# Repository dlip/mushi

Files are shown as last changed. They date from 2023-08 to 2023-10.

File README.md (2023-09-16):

# Mushi Keyboard

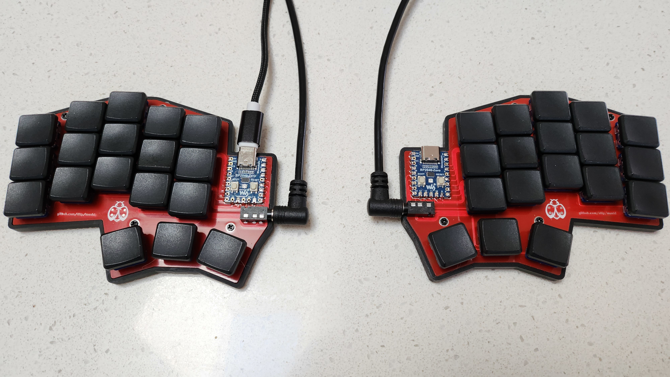
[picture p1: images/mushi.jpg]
Mushi Keyboard


Mushi (Japanese for bug) is a simple 36 key split ergonomic keyboard.

## Features

- Uses 2 cheap RP2040-Zero MCU
- Low profile Choc switches
- Hot swappable (optional)
- Requires no diodes
- Inner thumb splay to make it easier to reach
- Created with [Ergogen](https://github.com/ergogen/ergogen) and [KiCad](https://www.kicad.org)

## Build Your Own

### Board

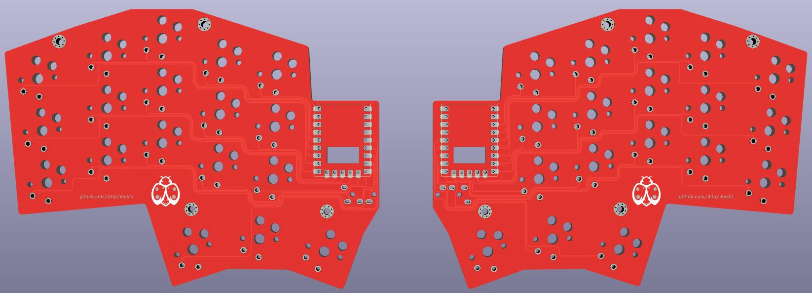
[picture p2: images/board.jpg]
Board


#### Parts

- Send the [Gerber](kicad/gerber_to_order) file to the PCB manufacturer of your choice
- 2 x RP2040-Zero
- 2 x TRRS socket
- 1 x TRRS cable
- 36 x low profile choc switches and keycaps
- (optional) 36 x kailh hotswap sockets
- (optional) RP2040-Zero headers

#### Instructions

- Solder the RP2040-Zeros to the board either directly or using the headers you purchased
- Build and flash the firmware
- [QMK](https://github.com/dlip/qmk_firmware/tree/dlip/keyboards/mushi)

Left side

```
qmk flash -kb mushi -km default -bl uf2-split-left
```

Right side

```
qmk flash -kb mushi -km default -bl uf2-split-right
```

- You can test the boards at this point by connecting the hotswap pads with some metal tweezers before continuing
- Solder the kalih hotswap sockets if purchased or solder the switches directly the board otherwise
- Solder the TRRS sockets to the board
- Insert the switches into the hotswap sockets if necessary
- Add your keycaps
- Connect TRRS cable before connecting the usb cable and remember to disconnect it after disconnecting the usb cable
- Create your own keymap by forking my repo and either modifying the default keymap or copying it to a new name and changing 'default' in the flash command

### Case

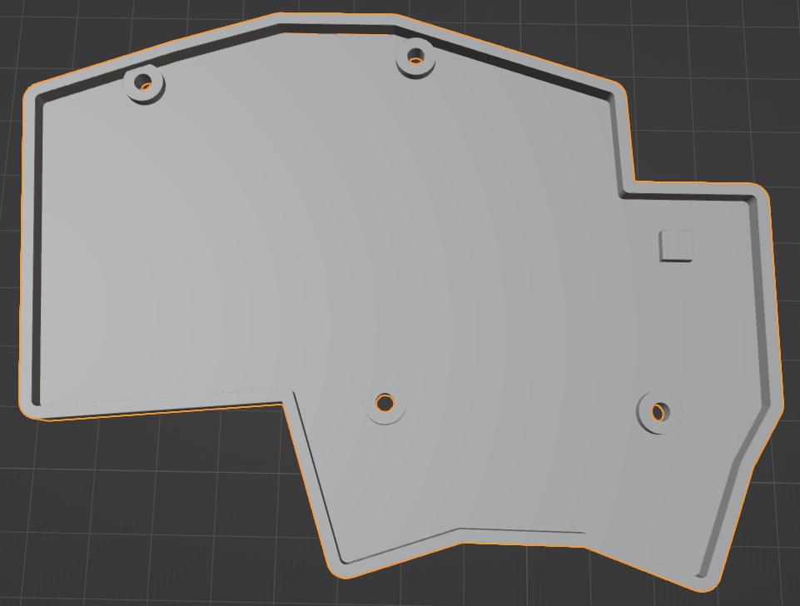
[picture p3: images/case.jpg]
Case


#### Parts

- 3D print the left and right cases in the [case](case/) folder
- 8 x Knurled Insert Nuts (M2 x 3mm Length x 3.2mm OD) [example](https://www.amazon.com/dp/B07LBQFNQD)
- 8 x M2 3mm flat screws [example](https://www.amazon.com/gp/product/B01FTI8TM8/)
- 10-16 x Rubber feet

#### Instructions

- Use a soldering iron to melt the insert nuts into the holes in the cases
- Screw the boards to the cases
- Stick rubber feet to bottom

### Credits

- alinelena for checking my work and helping me make such beautiful tracks
- logturnal for the cool [bug logo](https://www.freepik.com/free-vector/ladybug-simple-mascot-logo-design-illustration_57161077.htm)

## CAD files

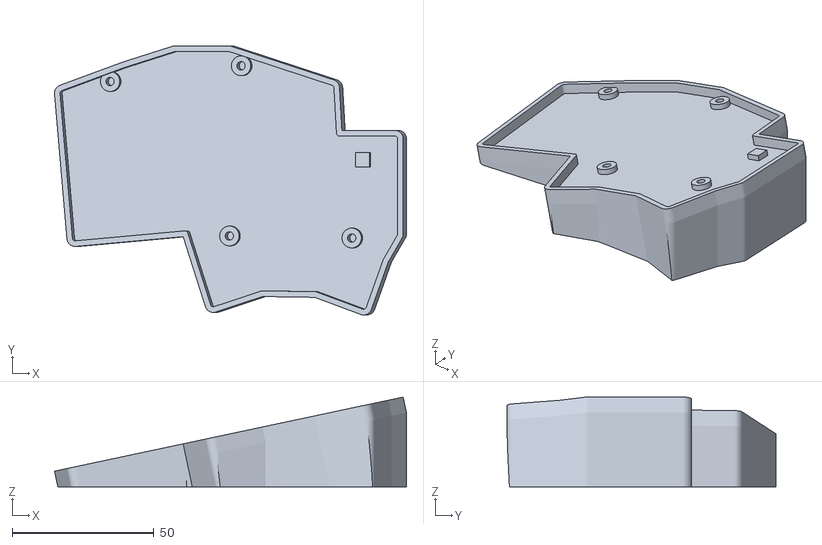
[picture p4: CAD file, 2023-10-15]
case/tenting.stl
124.1 x 94.8 x 31.7

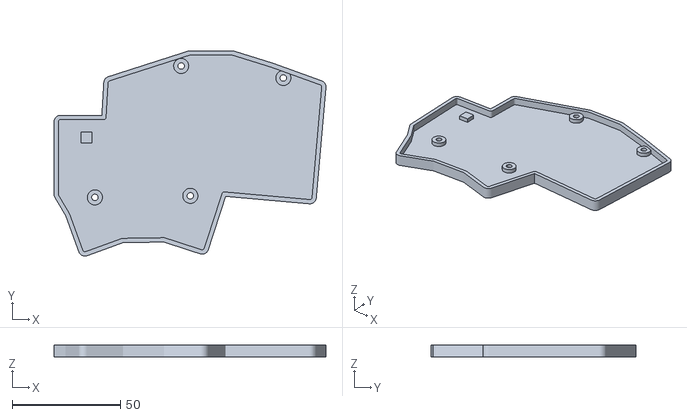
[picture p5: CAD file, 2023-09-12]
case/caseRight.stl
125.7 x 94.8 x 5.60

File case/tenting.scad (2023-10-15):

$fn = 40;
tent = 12;

intersection() {
	linear_extrude(100) rotate([0, -tent, 0]) translate([-14,0,0])  import("../output/outlines/xlBoardLeft.dxf", convexity=10);
	translate([0,0,0]) rotate([0, -tent, 0])	translate([-14,0,-100]) linear_extrude(100) import("../output/outlines/xlBoardLeft.dxf", convexity=10);
}
rotate([0, -tent, 0])	translate([-14,0,0]) import("caseLeft.stl", convexity=10);

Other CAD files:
case/caseLeft.stl

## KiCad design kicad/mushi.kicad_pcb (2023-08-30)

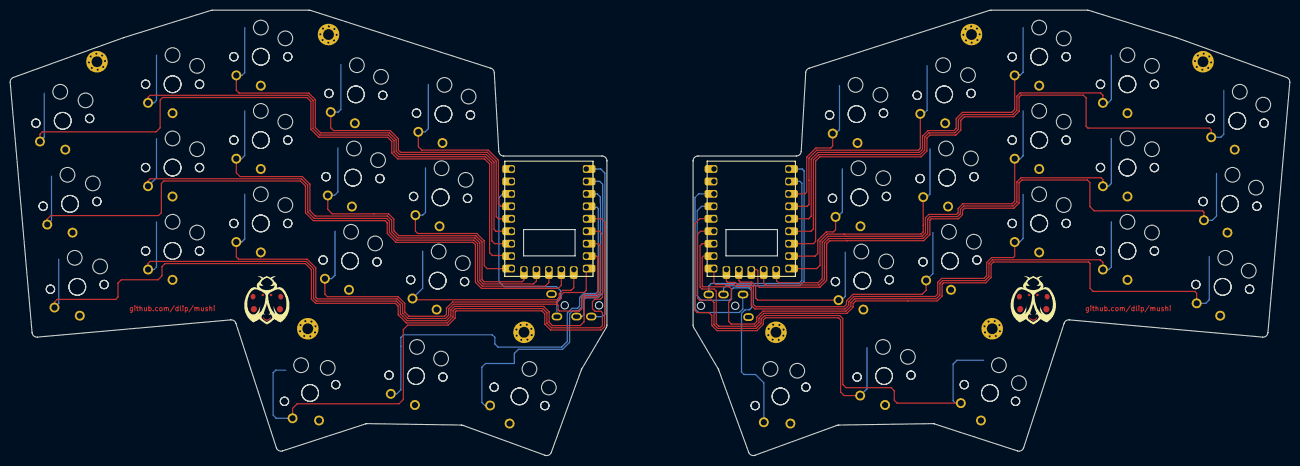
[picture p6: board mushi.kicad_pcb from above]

Board: 2 copper layers, 261.0 x 90.8 mm, 84 parts (0 on the bottom side), 44 nets.

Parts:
RP2040Zero1, RP2040Zero2: RP2040-Zero
S1, S2, S3, S4, S5, S6, S7, S8, S9, S10, S11, S12, S13, S14, S15, S16, S17, S18, S19, S20, S21, S22, S23, S24, S25, S26, S27, S28, S29, S30, S31, S32, S33, S34, S35, S36, S37, S38, S39, S40, S41, S42, S43, S44, S45, S46, S47, S48, S49, S50, S51, S52, S53, S54, S55, S56, S57, S58, S59, S60, S61, S62, S63, S64, S65, S66, S67, S68, S69, S70, S71, S72: PG1350
TRRS1, TRRS2: TRRS-PJ-320A-dual
_1, _2, _3, _4, _5, _6, _7, _8: MountingHole_2.2mm_M2_Pad_Via

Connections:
GND: RP2040Zero1.20, S1.2, S2.2, S3.2, S4.2, S5.2, S6.2, S7.2, S8.2, S9.2, S10.2, S11.2, S12.2, S13.2, S14.2, S15.2, S16.2, S17.2, S18.2, S19.2, S20.2, S21.2, S22.2, S23.2, S24.2, S25.2, S26.2, S27.2, S28.2, S29.2, S30.2, S31.2, S32.2, S33.2, S34.2, S35.2, S36.2, TRRS1.1
P3V3: RP2040Zero1.21, TRRS1.2
RX: RP2040Zero1.2, TRRS1.3
TX: RP2040Zero1.1, TRRS1.4
matrix_index_bottom: RP2040Zero1.9, S10.1, S28.1
matrix_index_middle: RP2040Zero1.14, S11.1, S29.1
matrix_index_top: RP2040Zero1.22, S12.1, S30.1
matrix_middle_bottom: RP2040Zero1.8, S7.1, S25.1
matrix_middle_middle: RP2040Zero1.13, S8.1, S26.1
matrix_middle_top: RP2040Zero1.18, S9.1, S27.1
matrix_outer_bottom: RP2040Zero1.10, S13.1, S31.1
matrix_outer_middle: RP2040Zero1.15, S14.1, S32.1
matrix_outer_top: RP2040Zero1.23, S15.1, S33.1
matrix_pinky_bottom: RP2040Zero1.6, S1.1, S19.1
matrix_pinky_middle: RP2040Zero1.11, S2.1, S20.1
matrix_pinky_top: RP2040Zero1.16, S3.1, S21.1
matrix_ring_bottom: RP2040Zero1.7, S4.1, S22.1
matrix_ring_middle: RP2040Zero1.12, S5.1, S23.1
matrix_ring_top: RP2040Zero1.17, S6.1, S24.1
mirror_matrix_index_bottom: RP2040Zero2.14, S46.1, S64.1
mirror_matrix_index_middle: RP2040Zero2.9, S47.1, S65.1
mirror_matrix_index_top: RP2040Zero2.4, S48.1, S66.1
mirror_matrix_middle_bottom: RP2040Zero2.15, S43.1, S61.1
mirror_matrix_middle_middle: RP2040Zero2.10, S44.1, S62.1
mirror_matrix_middle_top: RP2040Zero2.5, S45.1, S63.1
mirror_matrix_outer_bottom: RP2040Zero2.13, S49.1, S67.1
mirror_matrix_outer_middle: RP2040Zero2.8, S50.1, S68.1
mirror_matrix_outer_top: RP2040Zero2.3, S51.1, S69.1
mirror_matrix_pinky_bottom: RP2040Zero2.17, S37.1, S55.1
mirror_matrix_pinky_middle: RP2040Zero2.12, S38.1, S56.1
mirror_matrix_pinky_top: RP2040Zero2.7, S39.1, S57.1
mirror_matrix_ring_bottom: RP2040Zero2.16, S40.1, S58.1
mirror_matrix_ring_middle: RP2040Zero2.11, S41.1, S59.1
mirror_matrix_ring_top: RP2040Zero2.6, S42.1, S60.1
mirror_thumbs_inner_cluster: RP2040Zero2.18, S52.1, S70.1
mirror_thumbs_middle_cluster: RP2040Zero2.22, S53.1, S71.1
mirror_thumbs_outer_cluster: RP2040Zero2.23, S54.1, S72.1
rGND: RP2040Zero2.20, S37.2, S38.2, S39.2, S40.2, S41.2, S42.2, S43.2, S44.2, S45.2, S46.2, S47.2, S48.2, S49.2, S50.2, S51.2, S52.2, S53.2, S54.2, S55.2, S56.2, S57.2, S58.2, S59.2, S60.2, S61.2, S62.2, S63.2, S64.2, S65.2, S66.2, S67.2, S68.2, S69.2, S70.2, S71.2, S72.2, TRRS2.1
rP3V3: RP2040Zero2.21, TRRS2.2
rRX: RP2040Zero2.2, TRRS2.4
rTX: RP2040Zero2.1, TRRS2.3
thumbs_inner_cluster: RP2040Zero1.5, S16.1, S34.1
thumbs_middle_cluster: RP2040Zero1.4, S17.1, S35.1
thumbs_outer_cluster: RP2040Zero1.3, S18.1, S36.1

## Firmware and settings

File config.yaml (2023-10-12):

units:
  # Proxy Spacing Variables
  kx: cx
  ky: cy
  # Padding Variables
  px: kx + 2
  py: ky + 2
  # Double Padding Variables
  dpx: kx + 8
  dpy: ky + 8
  # M2 Screw Inserts
  screwRadius: 1.50
  standoffThickness: 2
  standoffDepth: 2
  # Case
  pcbThickness: 1.6
  baseThickness: 2
  wallThickness: 2
  # Footprints
  rp2040zero_x: 18
  rp2040zero_y: 23.5
  trrs_x: 12
  trrs_y: 6
points:
  zones:
    matrix:
      anchor:
        shift: [30, -80]
      key:
        padding: 1ky
        spread: 1kx
      columns:
        pinky:
          key:
            splay: 5
        ring:
          key:
            stagger: 0.33ky
            splay: -5
            spread: 1kx + 2
        middle:
          key:
            stagger: 0.33ky
        index:
          key:
            stagger: -0.45ky
            splay: -2
            spread: 1kx + 0.2
        outer:
          key:
            stagger: -0.2ky
            spread: 1kx
      rows:
        bottom:
        middle:
        top:
    thumbs:
      key:
        padding: 1kx
        spread: 1ky
      anchor:
        ref: matrix_outer_bottom
        shift: [-1.4kx, -1.4ky]
      columns:
        inner:
          key:
            width: 1.5kx
            splay: 20
        middle:
          key:
            width: 1.5kx
            splay: -20
            spread: 1.2kx
            stagger: -0.2ky
        outer:
          key:
            width: 1.5kx
            splay: -18
            spread: 1.25ky
            stagger: -0.2ky
      rows:
        cluster:
    mcu:
      anchor:
        ref: matrix_middle_top
        shift: [3.2kx, -2ky]
      key:
        width: rp2040zero_x
        height: rp2040zero_y
    trrs:
      anchor:
        ref: mcu
        shift: [7, -rp2040zero_x]
      key:
        width: trrs_x
        height: trrs_y
    holePinkyTop:
      anchor:
        ref: [matrix_pinky_top]
        shift: [0.4px,0.6py]
    holeIndexTop:
      anchor:
        ref: [matrix_index_top]
        shift: [-0.3px, 12]
    holeInnerThumbs:
      anchor:
        ref: [thumbs_inner_cluster]
        shift: [0.2kx, 0.7kx]
    holeOuterThumbs:
      anchor:
        ref: [thumbs_outer_cluster]
        shift: [-0.2kx, 0.7kx]
    support:
      anchor:
        ref: [mcu]
        shift: [0, 0.3kx]
  mirror: &mirror
    ref: matrix_index_top
    distance: 120
outlines:
  keys:
    - what: rectangle
      where: /matrix|thumb/
      size: [kx-0.5,ky-0.5]
  boardLeft:
    - what: polygon
      operation: stack
      fillet: 1
      points:
        - ref: matrix_pinky_top
          shift: [-0.5px,0.5py]
        - ref: matrix_ring_top
          shift: [-0.5px,0.5py]
        - ref: matrix_middle_top
          shift: [-0.5px,0.5py]
        - ref: matrix_middle_top
          shift: [0.5px,0.5py]
        - ref: matrix_outer_top
          shift: [0.5px,0.5py]
        - ref: mcu
          shift: [-rp2040zero_x/2,rp2040zero_y/2+2]
        - ref: mcu
          shift: [rp2040zero_x/2+4,rp2040zero_y/2+2]
        - ref: trrs
          shift: [trrs_x/2,-trrs_y/2]
        - ref: thumbs_outer_cluster
          shift: [0.5px,0.5py]
        - ref: thumbs_outer_cluster
          shift: [0.5px,-0.5py]
        - ref: thumbs_outer_cluster
          shift: [-0.45px,-0.5py]
        - ref: thumbs_inner_cluster
          shift: [0.45px,-0.5py]
        - ref: thumbs_inner_cluster
          shift: [-0.5px,-0.5py]
        - ref: thumbs_inner_cluster
          shift: [-0.5px,1py]
        - ref: matrix_pinky_bottom
          shift: [-0.5px,-0.5py]
  boardRight:
    - what: polygon
      operation: stack
      fillet: 1
      points:
        - ref: mirror_matrix_pinky_top
          shift: [-0.5px,0.5py]
        - ref: mirror_matrix_ring_top
          shift: [-0.5px,0.5py]
        - ref: mirror_matrix_middle_top
          shift: [-0.5px,0.5py]
        - ref: mirror_matrix_middle_top
          shift: [0.5px,0.5py]
        - ref: mirror_matrix_outer_top
          shift: [0.5px,0.5py]
        - ref: mirror_mcu
          shift: [-rp2040zero_x/2,rp2040zero_y/2+2]
        - ref: mirror_mcu
          shift: [rp2040zero_x/2+4,rp2040zero_y/2+2]
        - ref: mirror_trrs
          shift: [trrs_x/2,-trrs_y/2]
        - ref: mirror_thumbs_outer_cluster
          shift: [0.5px,0.5py]
        - ref: mirror_thumbs_outer_cluster
          shift: [0.5px,-0.5py]
        - ref: mirror_thumbs_outer_cluster
          shift: [-0.45px,-0.5py]
        - ref: mirror_thumbs_inner_cluster
          shift: [0.45px,-0.5py]
        - ref: mirror_thumbs_inner_cluster
          shift: [-0.5px,-0.5py]
        - ref: mirror_thumbs_inner_cluster
          shift: [-0.5px,1py]
        - ref: mirror_matrix_pinky_bottom
          shift: [-0.5px,-0.5py]
  board:
    - boardLeft
    - boardRight
  _mcu:
    - what: rectangle
      where: /mcu/
      size: [rp2040zero_x, rp2040zero_y]
  _trrs:
    - what: rectangle
      where: /trrs/
      size: [trrs_x, trrs_y] 
  xlBoardLeft:
    - what: outline
      name: boardLeft
      expand: wallThickness
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

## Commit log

2023-08-27 Add mushi
    [case.stl, mushi.kicad_pcb, mushi.kicad_sch]
2023-08-27 round tracks
    [mushi.kicad_pcb]
2023-08-27 separate rounded
    [mushi_rounded.kicad_pcb]
2023-08-28 remove empty segment
    [mushi.kicad_pcb]
2023-08-28 thinner case
    [case.stl]
2023-08-28 improve rounded
    [mushi-rounded.kicad_pcb]
2023-08-29 smooth right side
    [mushi.kicad_pcb]
2023-08-29 cleanup left side
    [mushi.kicad_pcb]
2023-08-29 clean up gnd
    [mushi.kicad_pcb]
2023-08-29 more cleanup
    [mushi.kicad_pcb]
2023-08-29 new zones and logo
    [mushi.kicad_pcb]
2023-08-30 update logos
    [mushi.kicad_pcb]
2023-08-30 revert track rounding
    [mushi.kicad_pcb]
2023-08-30 remove duplicate text
    [mushi.kicad_pcb]
2023-08-30 Round tracks and export gerber
2023-08-30 regenerate gerbers
2023-08-31 Separate left and right cases
    [case.stl, caseLeft.stl, caseRight.stl]
2023-09-10 Add board
2023-09-10 add case
2023-09-12 Increase standoff depth
    [caseLeft.stl, caseRight.stl]
2023-09-12 Extend holes for case
    [caseLeft.stl, caseRight.stl]
2023-10-12 Add tenting scad
    [tenting.scad]
2023-10-15 Add tenting case
    [tenting.scad, tenting.stl]
